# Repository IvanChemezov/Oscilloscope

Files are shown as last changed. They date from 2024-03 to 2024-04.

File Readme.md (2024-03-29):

# Description of the project
Schematic
## Goals:
Learn more about electronics via DIYproject. Technologies which need to be used and learned are: low noise readout electronics, USB as a main data line, space compound. Shielding of pcbs,  wireless connection - additional.

## DIY project:
A portable USB, 1 channel oscilloscope version 1. 

## Activities:
Define Project Requirements;
Conceptualization (diagrams);
Feasibility Study (costs, time);
Define the components for design;
Find and order devboards of the components;
Develop preliminary design of the system;
Prepare and check the schematic;
Order components;
Testing and debugging software;
Prepare and check the pcb layout;
Manufacture the pcb;
Execute test procedure;
Testing and debugging software;
Move to next version of design which includes wireless communication modules;

## Requirements: 
Number of Channels - The oscilloscope should be a single channel.
Bandwidth - The input network bandwidth should support frequencies up to 10 MHz.
Input Impedance - The oscilloscope's input impedance should be 1 MOhm || 15 pF.
Input Signal Range - The acceptable input signal range is -5 V to +5 V.
Time Division -  min. time division of 0.1 us,  max. time 1 seconds.
Vertical Offset - Vertical offset should range from -40 to +40 divisions, with vertical resolution sensitivity set at 40 divisions.
Connector - The oscilloscope should be equipped with a BNC connector for the probes.
ADC Specifications - The ADC resolution > 12 bits, sampling frequency > 10 MHz.
Power Source - The oscilloscope should be powered through a USB Type-A connection.
Display - The device does not have a display. Data shown on a laptop
*Memory Capacity - The oscilloscope's memory capacity should be > 1 MB, TBD, optional*.
Operating Modes - The oscilloscope should support different operating modes, including normal, peak detect, average, and high-resolution modes.

## Design solution
Scope should have a status RGB LED.
Oscilloscope shouldn’t have any user’s buttons or switches
Device should include protection mechanisms against ESD and overloading.
The main processor should be a high performance MCU with maths acceleration functions (ex. STM32G484).
The main ADC should be compatible with pin-to-pin replacements, such as AD9235, ads4122-ads4129, ADC10080 - ADC10040, LTC2245. The ADCs have to have same interface 
Wireless Connectivity - The oscilloscope should include a Wi-Fi chip with support for 802.11n or superior standards.
Components should have minimal footprint.
Pcb needs to be as small as possible, preferable 30 x 20

## Success metrics:
Oscilloscope match the required parameters, technologies are working as estimated

## Reference project
https://www.martinloren.com/hs101-pro-diy-oscilloscope/ 

## Components
Mcu test  
https://eu.mouser.com/ProductDetail/STMicroelectronics/NUCLEO-G474RE?qs=T3oQrply3y%2FWWTZ0gC%252Br%2FA%3D%3D 

## Open questions
https://eu.mouser.com/ProductDetail/STMicroelectronics/STM32G491KCU6?qs=CiayqK2gdcJMDdaGLIKprw%3D%3D controller
https://eu.mouser.com/ProductDetail/Analog-Devices/LTC2225CUHPBF?qs=hVkxg5c3xu%252B3BqQYArDo0w%3D%3D ADC
https://eu.mouser.com/ProductDetail/GigaDevice/GD25D10CEIGR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 memory
https://eu.mouser.com/ProductDetail/Toshiba/TCR15AG33LF?qs=W0yvOO0ixfEdwQi51FhISQ%3D%3D power
https://eu.mouser.com/ProductDetail/Amphenol-RF/112640?qs=g6wJ%252BjiQWOckvE%2FP9L4wAw%3D%3D connector
https://eu.mouser.com/ProductDetail/Masach/MS110-10S?qs=pUKx8fyJudBF3ymdfEXpvw%3D%3D shielding
https://eu.mouser.com/datasheet/2/609/AD8337-3119375.pdf preamplifier
https://eu.mouser.com/ProductDetail/Inolux/IN-S63TBS5R5G5B?qs=stqOd1AaK7%2Fi2QYkhDu%252BwA%3D%3D rgb led
https://eu.mouser.com/ProductDetail/Hirose-Connector/CX60-24S-UNIT?qs=W0yvOO0ixfHwfoCnP4i0Tw%3D%3D usb type C
https://eu.mouser.com/ProductDetail/Analog-Devices/ADA4830-1WBCPZ-R7?qs=pqQDoYZ2quZZWZQMT6uc6g%3D%3D difference amplifier

## Reference designs
https://www.instructables.com/DPScope-Build-Your-Own-USBPC-Based-Oscilloscope/
https://www.bitscope.com/product/BS05/ 
https://github.com/martinloren/HScope/blob/master/HS402/V3.0%2BWifi/Schematic%26PCB/SCH_HS402-WIFI_V3.1_220108.pdf 
https://hackaday.com/2023/10/18/stm32-offers-performance-gains-for-diy-oscilloscope/ 
https://www.youtube.com/watch?v=cVnVtucYcDg&ab_channel=STMicroelectronics

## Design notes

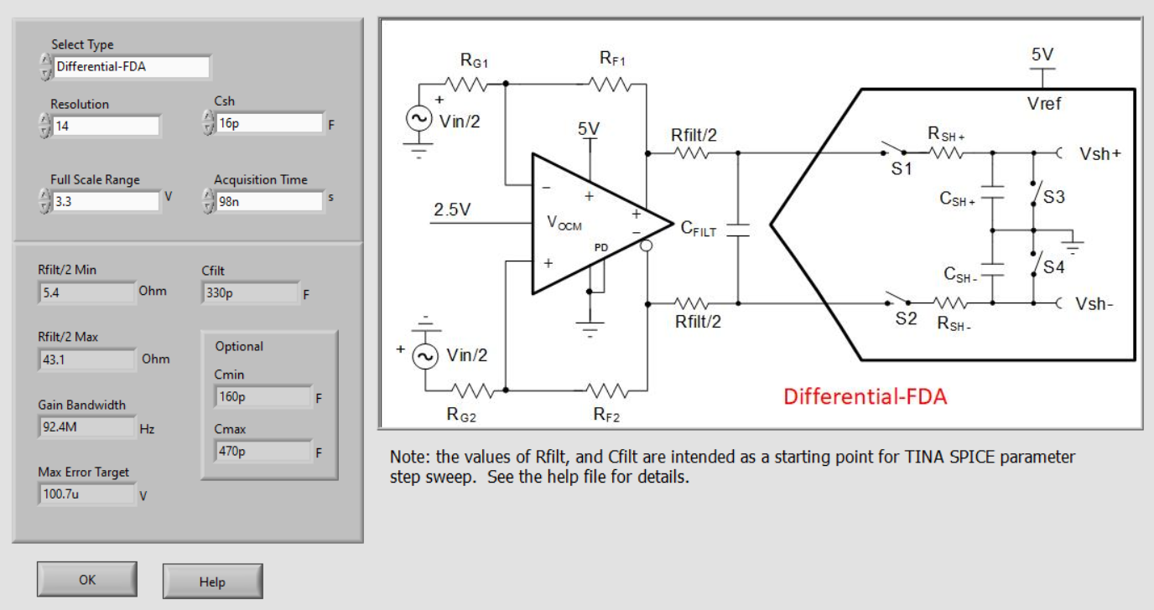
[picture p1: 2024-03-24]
Scope_evtA/Amp.png

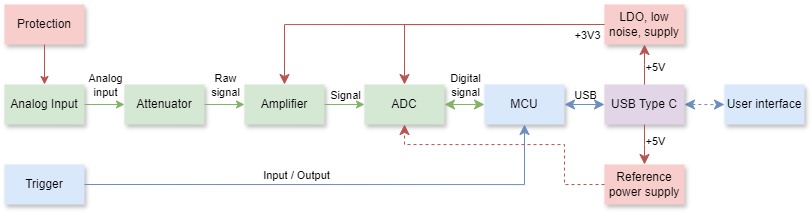
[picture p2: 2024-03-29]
Scope_evtA/scope.jpg

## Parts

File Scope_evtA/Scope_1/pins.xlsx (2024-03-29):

# | Port | Pin | Function | Name | Comment
1 | N/A | N/A | Power | Vdd
2 | C | 13 | NC | N/A
3 | C | 14 | NC | N/A
4 | C | 15 | NC | N/A
5 | F | 0 | OSC+ | N/A
6 | F | 1 | OSC- | N/A
7 | G | 0 | NC | N/A
8 | A | 0 | TIM2_1 | ADC_CLK | Up to 20 MHz
9 | A | 1 | Output | Mode_1 | Twos Complement
10 | A | 2 | Output | Mode_2 | Offset Binary
11 | A | 3 | Comp2_Inp | Trigger
12 | A | 4 | DAC1_1 | Trigger_Out
13 | A | 5 | Input | OTR | From ADC
14 | A | 6 | Output | Sense | Need to be open drain
15 | A | 7 | Output | PDWN | ADC on/off
16 | C | 4 | NC | N/A
17 | B | 0 | Input | D0 | From ADC data line
18 | B | 1 | Input | D1 | From ADC data line
19 | B | 2 | Input | D2 | From ADC data line
20 | N/A | N/A | Power | Vdda
21 | N/A | N/A | Power | Vdda
22 | B | 10 | Input | D10 | From ADC data line
23 | N/A | N/A | Power | Vdd
24 | B | 11 | Input | D11 | From ADC data line
25 | B | 12 | Input | D12 | From ADC data line
26 | B | 13 | Input | D13 | From ADC data line
27 | B | 14 | NC | N/A
28 | B | 15 | NC | N/A
29 | C | 6 | NC | N/A
30 | A | 8 | NC | N/A
31 | A | 9 | TIM1_2 | PWM_LED | For WS2812
32 | A | 10 | Output | USB_Pin | Reboot USB isolator
33 | A | 11 | USB | USB_N
34 | A | 12 | USB | USB_P
35 | N/A | N/A | Power | Vdd
36 | A | 13 | SWDIO | SWDIO
37 | A | 14 | SWCLK | SWCLK
38 | A | 15 | NC | N/A
39 | C | 10 | NC | N/A
40 | C | 11 | NC | N/A
41 | B | 3 | Input | D3 | From ADC data line
42 | B | 4 | Input | D4 | From ADC data line
43 | B | 5 | Input | D5 | From ADC data line
44 | B | 6 | Input | D6 | From ADC data line
45 | B | 7 | Input | D7 | From ADC data line
46 | B | 8 | Input | D8 | From ADC data line
47 | B | 9 | Input | D9 | From ADC data line
48 | N/A | N/A | Power | Vdd
49 | N/A | N/A | Vss | GND

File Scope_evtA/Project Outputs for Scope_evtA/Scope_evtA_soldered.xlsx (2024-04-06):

Comment | P/N | Designator | Footprint | Quantity
0R | SCR0603J0R | R13, R21 | R0603 | 2
0.1u | 06031C104K4T2A | C2, C4, C7, C8, C9, C10, C11, C13, C14, C20, C24, C27, C29, C32, C39, C42, C44, C47, C48, C50, C55, C58, C60, C61, C65, C66, C68, C69, C72, C74, C75, C76, C77, C79 | C0603 | 34
1M | AR03BTCX1004 | R6, R20 | R0603 | 2
1u | C0603X105K025T | C21, C22, C25, C30, C40, C46, C49, C56, C57, C59 | C0603 | 10
1.5k | TC0325B1501T5F | R14, R15, R17 | R0603 | 3
2.2n | 06035C222JAT2A | C5, C16, C34 | C0603 | 3
4.7uF | GRT188C71C475KE13D | C1, C3, C12, C15, C18, C19, C23, C26, C28, C31, C33, C36, C37, C38, C41, C43, C64, C67, C73, C78 | C0603 | 20
5k1 | SCR0603F5K1 | R4, R5, R42 | R0603 | 3
10k | SCR0603J10K | R10, R12, R23, R36, R40 | R0603 | 5
10p | 06035A100DAT2A | C51, C52, C62, C63, C70, C71 | C0603 | 6
20k | SCR0603J20K | R9, R11, R41 | R0603 | 3
22 R | SCR0603J22R | R2, R3, R16, R18, R22, R24, R25, R27, R28, R29, R30, R31, R32, R33, R34, R35, R37, R38, R39, R43, R44, R45, R46, R47, R49, R50, R51 | R0603 | 27
100R | RTT03101JTP | R26, R48 | R0603 | 2
390p | TCC0603COG391J500CT | C6, C17, C35, C45 | C0603 | 4
AD9245BCPZ-20 | AD9245BCPZ-20 | DA3 | LFCSP-32_AD9245 | 1
AP3012KTR-G1 | AP3012KTR-G1 | DD3 | SOT-23-5 | 1
REF35160QDBVR | REF35160QDBVR | DD2 | SOT-23-6 | 1
TPD2EUSB30ADRTR | TPD2EUSB30ADRTR | VD3 | SOT-9X3 | 1
TYPEC-309-ACP16L65 | TYPEC-309-ACP16L65 | J1 | 217179-0001 | 1
WS2812C | WS2812C | VD5 | SMD5050 | 1

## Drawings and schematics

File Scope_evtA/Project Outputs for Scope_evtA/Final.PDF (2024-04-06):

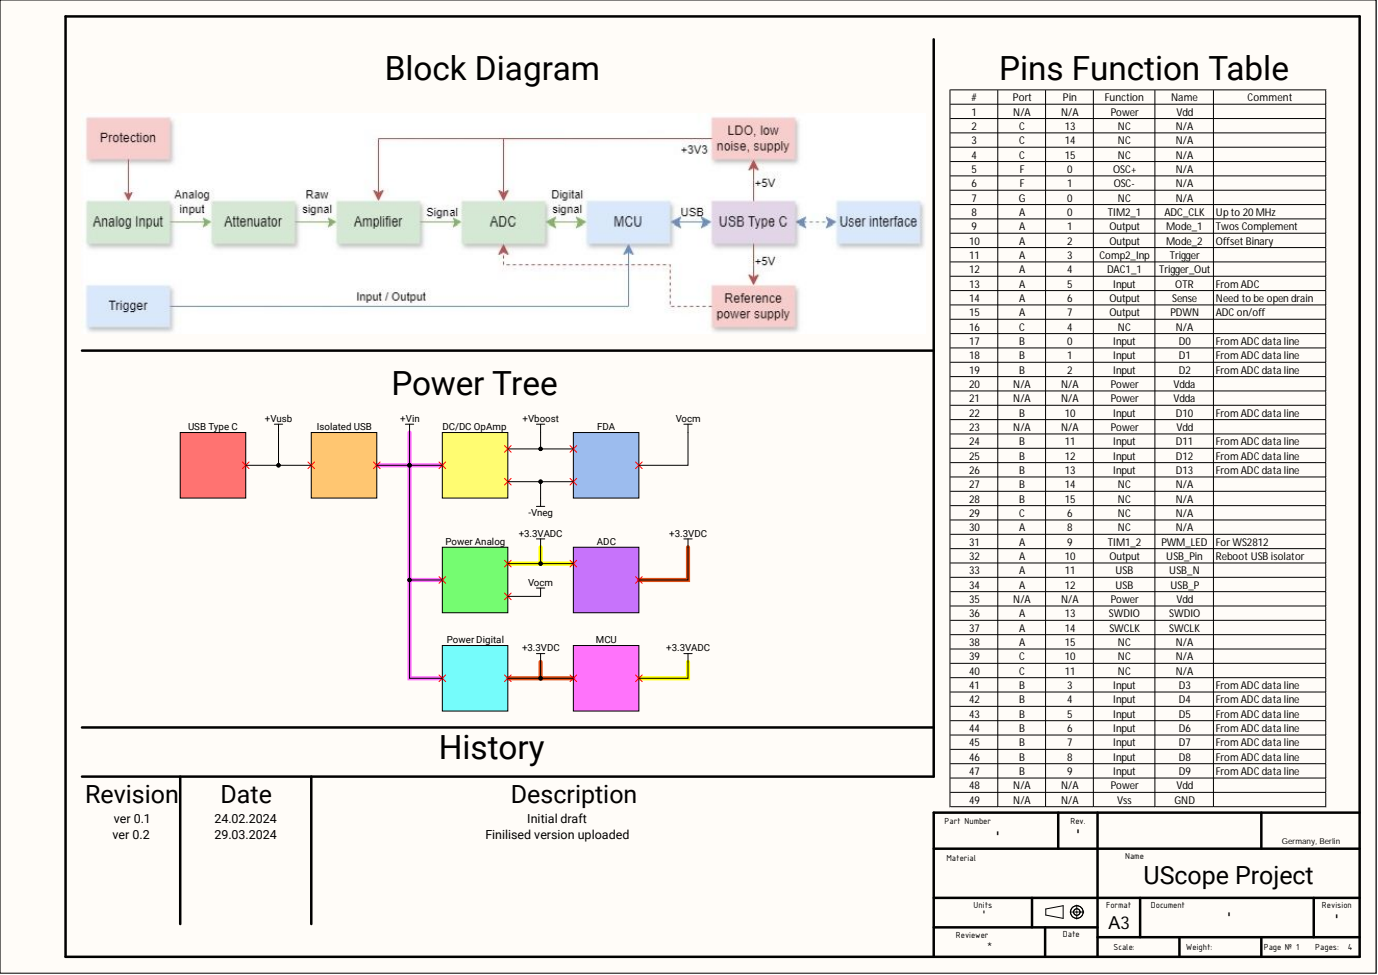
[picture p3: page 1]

# | Port | Pin | Function | Name | Comment
1 | N/A | N/A | Power | Vdd
2 | C | 13 | NC | N/A
3 | C | 14 | NC | N/A
4 | C | 15 | NC | N/A
5 | F | 0 | OSC+ | N/A
6 | F | 1 | OSC- | N/A
7 | G | 0 | NC | N/A
8 | A | 0 | TIM2_1 | ADC_CLK | Up to 20 MHz
9 | A | 1 | Output | Mode_1 | Twos Complement
10 | A | 2 | Output | Mode_2 | Offset Binary
11 | A | 3 | Comp2_Inp | Trigger
12 | A | 4 | DAC1_1 | Trigger_Out
13 | A | 5 | Input | OTR | From ADC
14 | A | 6 | Output | Sense | Need to be open drain
15 | A | 7 | Output | PDWN | ADC on/off
16 | C | 4 | NC | N/A
17 | B | 0 | Input | D0 | From ADC data line
18 | B | 1 | Input | D1 | From ADC data line
19 | B | 2 | Input | D2 | From ADC data line
20 | N/A | N/A | Power | Vdda
21 | N/A | N/A | Power | Vdda
22 | B | 10 | Input | D10 | From ADC data line
23 | N/A | N/A | Power | Vdd
24 | B | 11 | Input | D11 | From ADC data line
25 | B | 12 | Input | D12 | From ADC data line

27 | B | 14 | NC | N/A
28 | B | 15 | NC | N/A
29 | C | 6 | NC | N/A
30 | A | 8 | NC | N/A
31 | A | 9 | TIM1_2 | PWM_LED | For WS2812
32 | A | 10 | Output | USB_Pin | Reboot USB isolator

34 | A | 12 | USB | USB_P
35 | N/A | N/A | Power | Vdd
36 | A | 13 | SWDIO | SWDIO
37 | A | 14 | SWCLK | SWCLK
38 | A | 15 | NC | N/A
39 | C | 10 | NC | N/A
40 | C | 11 | NC | N/A
41 | B | 3 | Input | D3 | From ADC data line
42 | B | 4 | Input | D4 | From ADC data line
43 | B | 5 | Input | D5 | From ADC data line
44 | B | 6 | Input | D6 | From ADC data line
45 | B | 7 | Input | D7 | From ADC data line
46 | B | 8 | Input | D8 | From ADC data line
47 | B | 9 | Input | D9 | From ADC data line
48 | N/A | N/A | Power | Vdd
49 | N/A | N/A | Vss | GND

Part Number ' | Rev. ' | | Germany, Berlin

Material | | Name UScope Project

Units ' | | | | Format А3 | Document | Revision

Reviewer * | | Date

Scale: | Weight: | Page № 1 Pages: 4

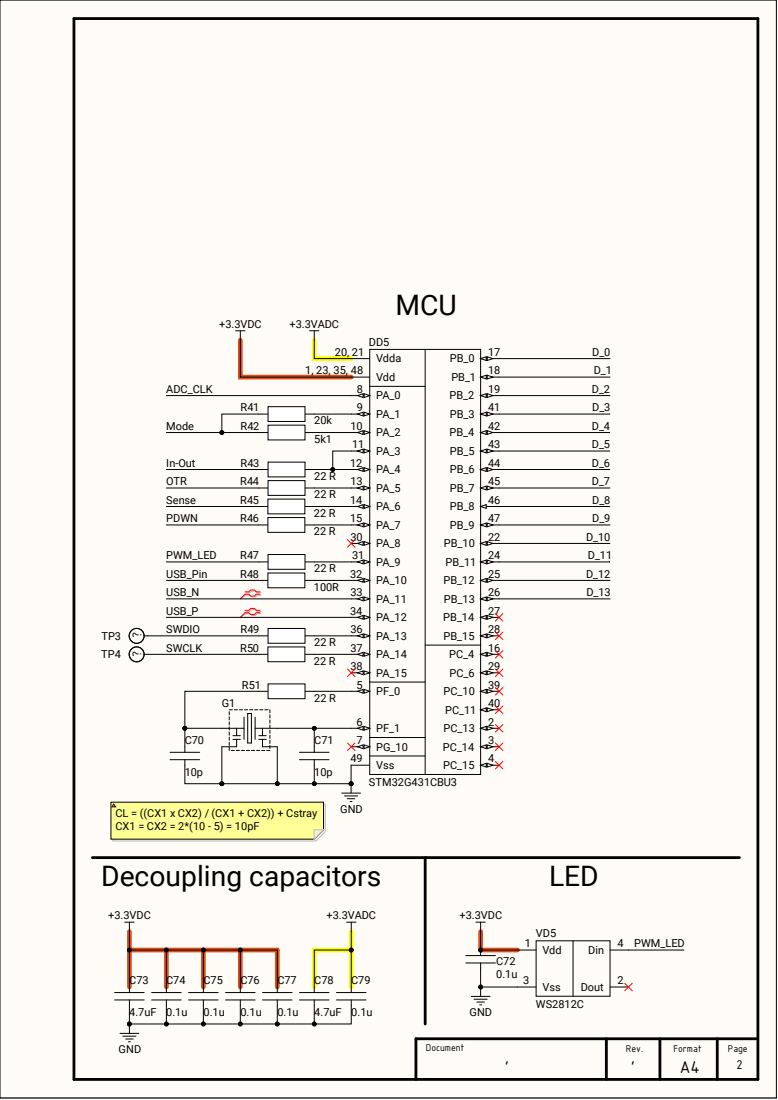
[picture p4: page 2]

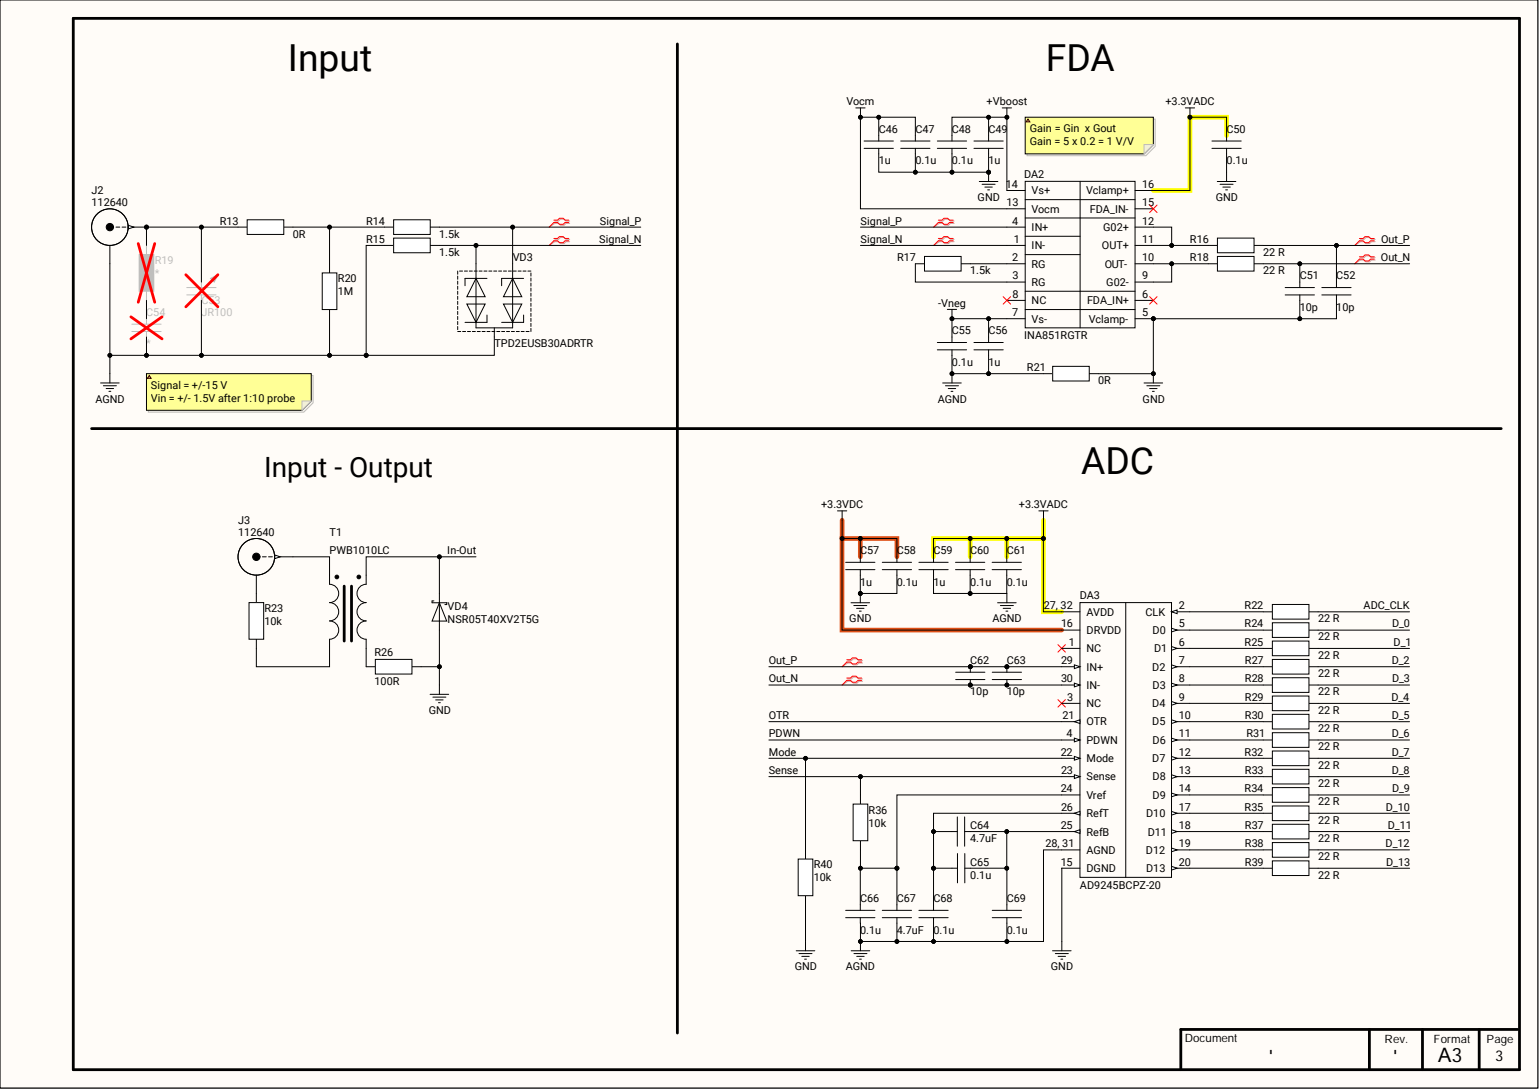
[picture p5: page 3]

RG 3
NC 8
Vs- 7

RefT 26
RefB 25
AGND 28, 31
DGND 15

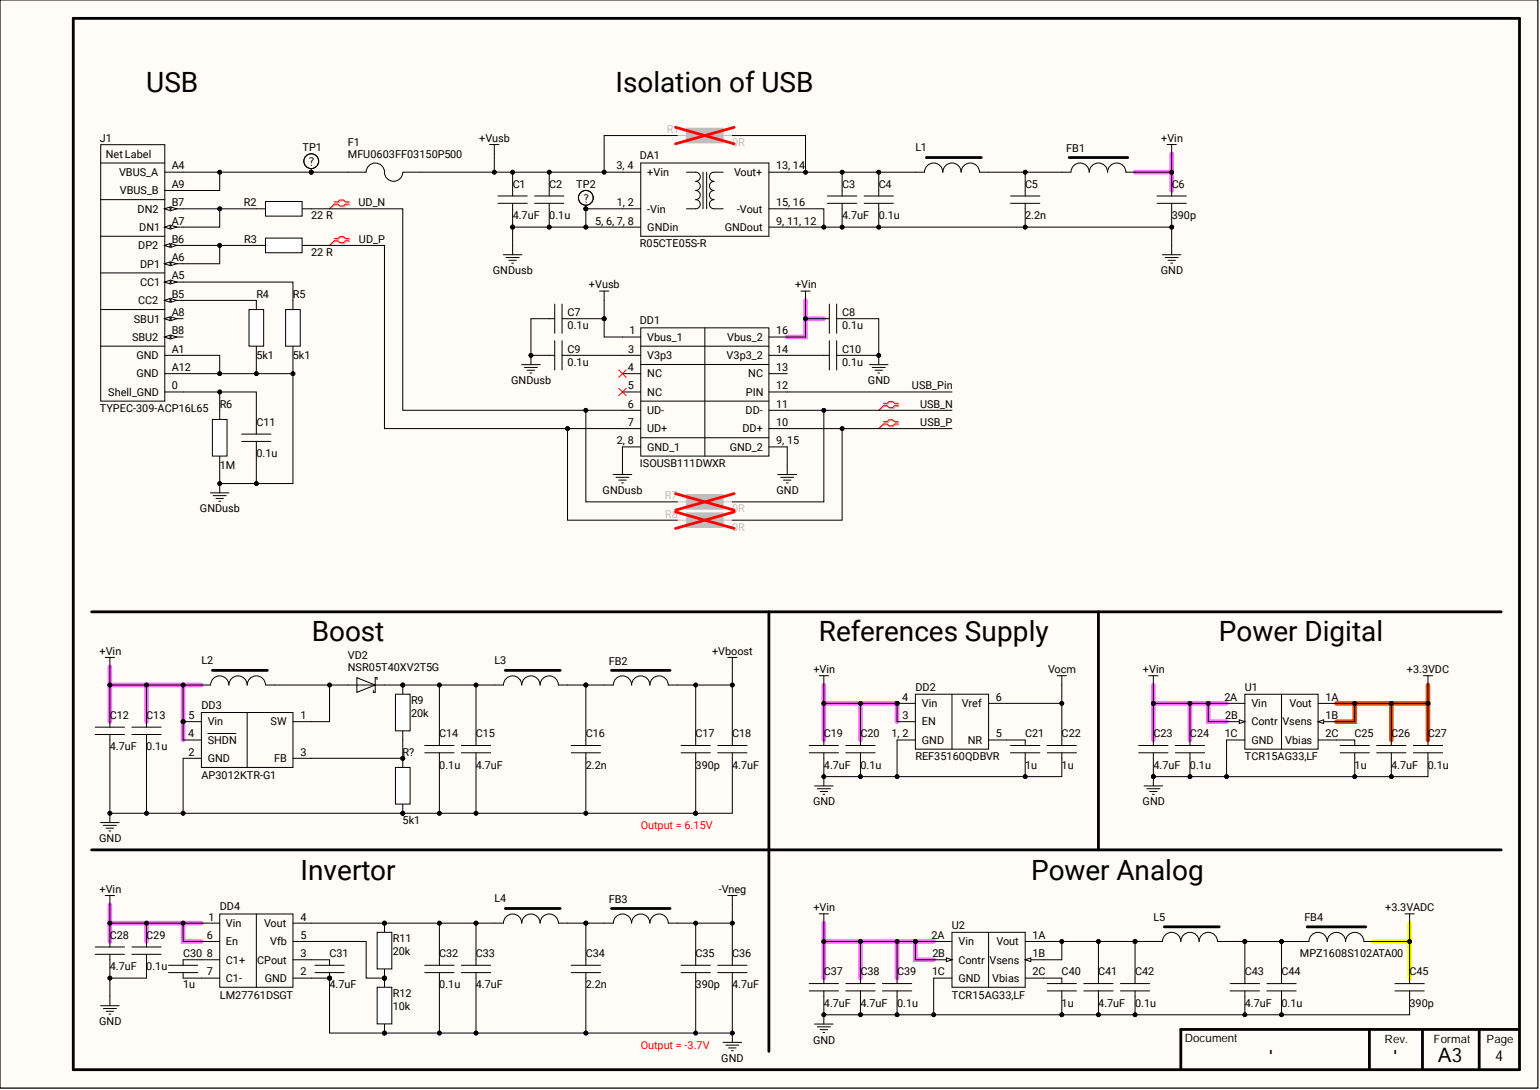
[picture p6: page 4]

+Vin 3, 4

Vbus_1 1
V3p3 3

Vin

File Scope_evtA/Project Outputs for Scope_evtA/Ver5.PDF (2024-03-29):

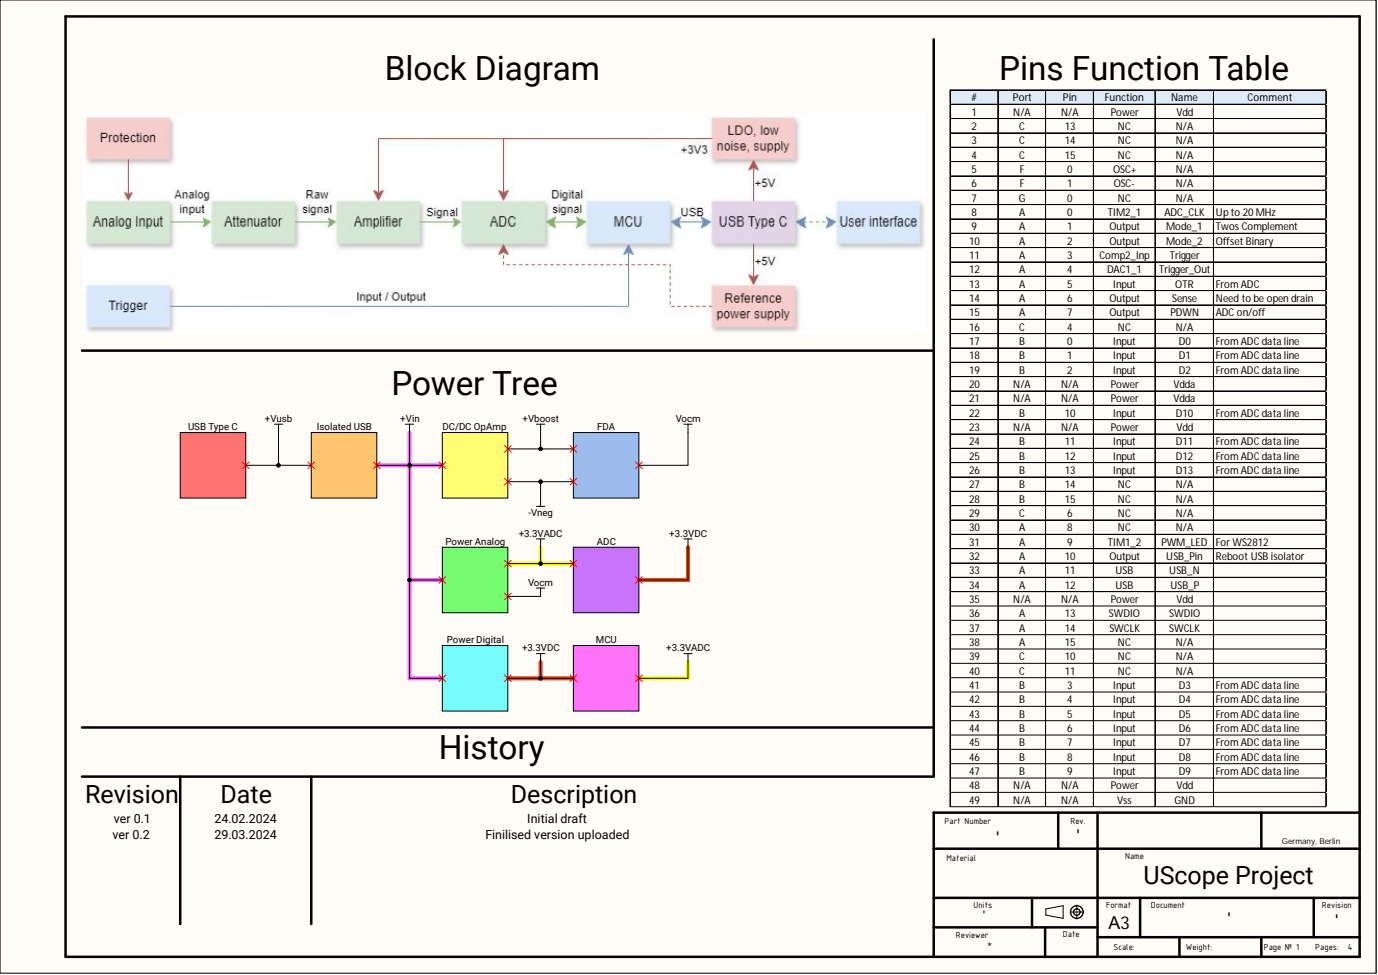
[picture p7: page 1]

# | Port | Pin | Function | Name | Comment
1 | N/A | N/A | Power | Vdd
2 | C | 13 | NC | N/A
3 | C | 14 | NC | N/A
4 | C | 15 | NC | N/A
5 | F | 0 | OSC+ | N/A
6 | F | 1 | OSC- | N/A
7 | G | 0 | NC | N/A
8 | A | 0 | TIM2_1 | ADC_CLK | Up to 20 MHz
9 | A | 1 | Output | Mode_1 | Twos Complement
10 | A | 2 | Output | Mode_2 | Offset Binary
11 | A | 3 | Comp2_Inp | Trigger
12 | A | 4 | DAC1_1 | Trigger_Out
13 | A | 5 | Input | OTR | From ADC
14 | A | 6 | Output | Sense | Need to be open drain
15 | A | 7 | Output | PDWN | ADC on/off
16 | C | 4 | NC | N/A
17 | B | 0 | Input | D0 | From ADC data line
18 | B | 1 | Input | D1 | From ADC data line
19 | B | 2 | Input | D2 | From ADC data line
20 | N/A | N/A | Power | Vdda
21 | N/A | N/A | Power | Vdda
22 | B | 10 | Input | D10 | From ADC data line
23 | N/A | N/A | Power | Vdd
24 | B | 11 | Input | D11 | From ADC data line
25 | B | 12 | Input | D12 | From ADC data line

27 | B | 14 | NC | N/A
28 | B | 15 | NC | N/A
29 | C | 6 | NC | N/A
30 | A | 8 | NC | N/A
31 | A | 9 | TIM1_2 | PWM_LED | For WS2812
32 | A | 10 | Output | USB_Pin | Reboot USB isolator

34 | A | 12 | USB | USB_P
35 | N/A | N/A | Power | Vdd
36 | A | 13 | SWDIO | SWDIO
37 | A | 14 | SWCLK | SWCLK
38 | A | 15 | NC | N/A
39 | C | 10 | NC | N/A
40 | C | 11 | NC | N/A
41 | B | 3 | Input | D3 | From ADC data line
42 | B | 4 | Input | D4 | From ADC data line
43 | B | 5 | Input | D5 | From ADC data line
44 | B | 6 | Input | D6 | From ADC data line
45 | B | 7 | Input | D7 | From ADC data line
46 | B | 8 | Input | D8 | From ADC data line
47 | B | 9 | Input | D9 | From ADC data line
48 | N/A | N/A | Power | Vdd
49 | N/A | N/A | Vss | GND

Part Number ' | Rev. ' | | Germany, Berlin

Material | | Name UScope Project

Units ' | | | | Format А3 | Document | Revision

Reviewer * | | Date

Scale: | Weight: | Page № 1 Pages: 4

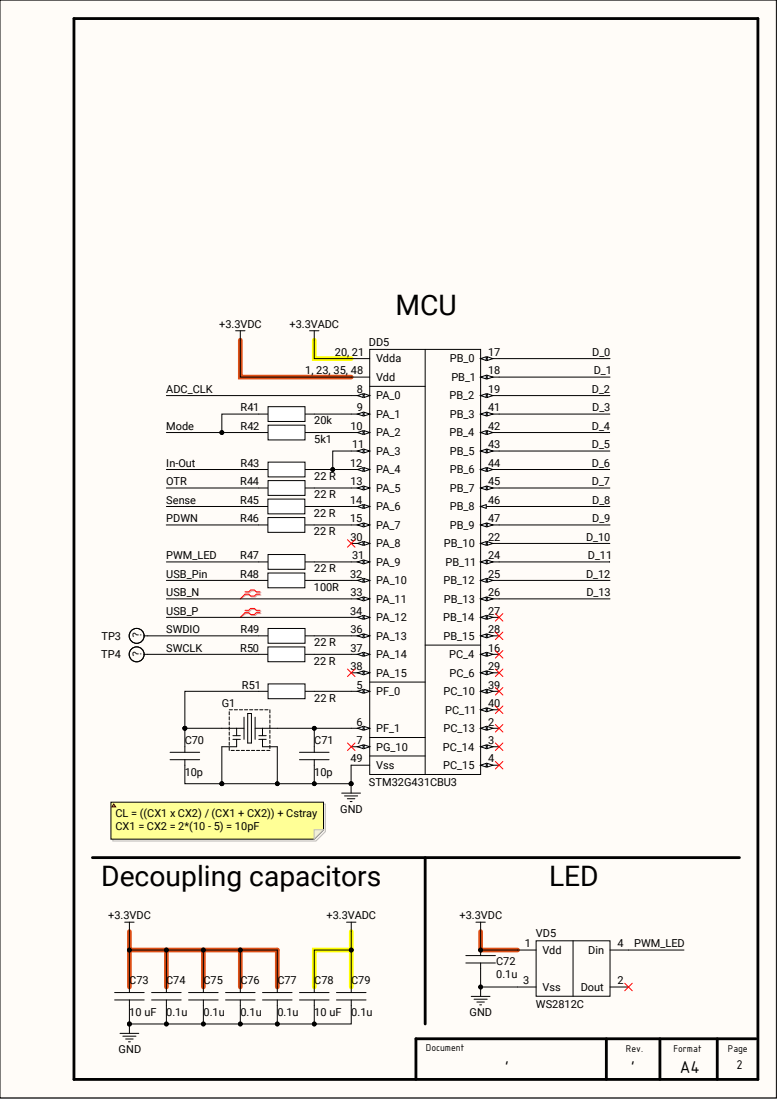
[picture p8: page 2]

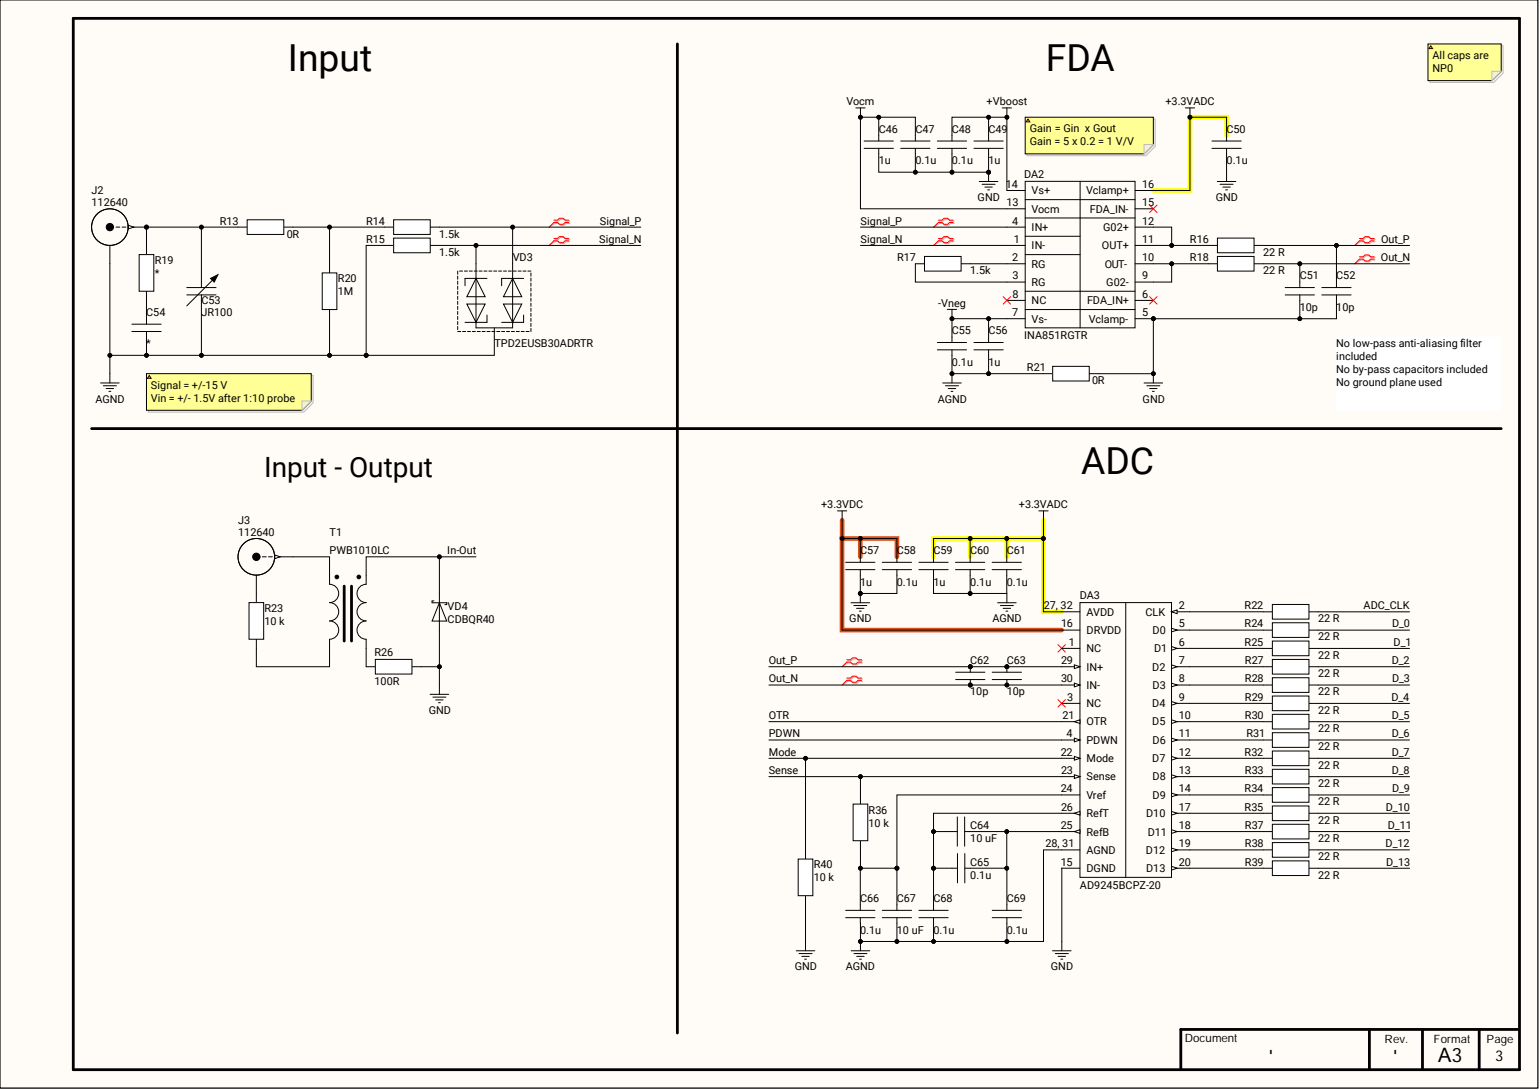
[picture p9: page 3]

RG 3
NC 8
Vs- 7

No low-pass anti-aliasing filter
included
No by-pass capacitors included
No ground plane used

RefT 26
RefB 25
AGND 28, 31
DGND 15

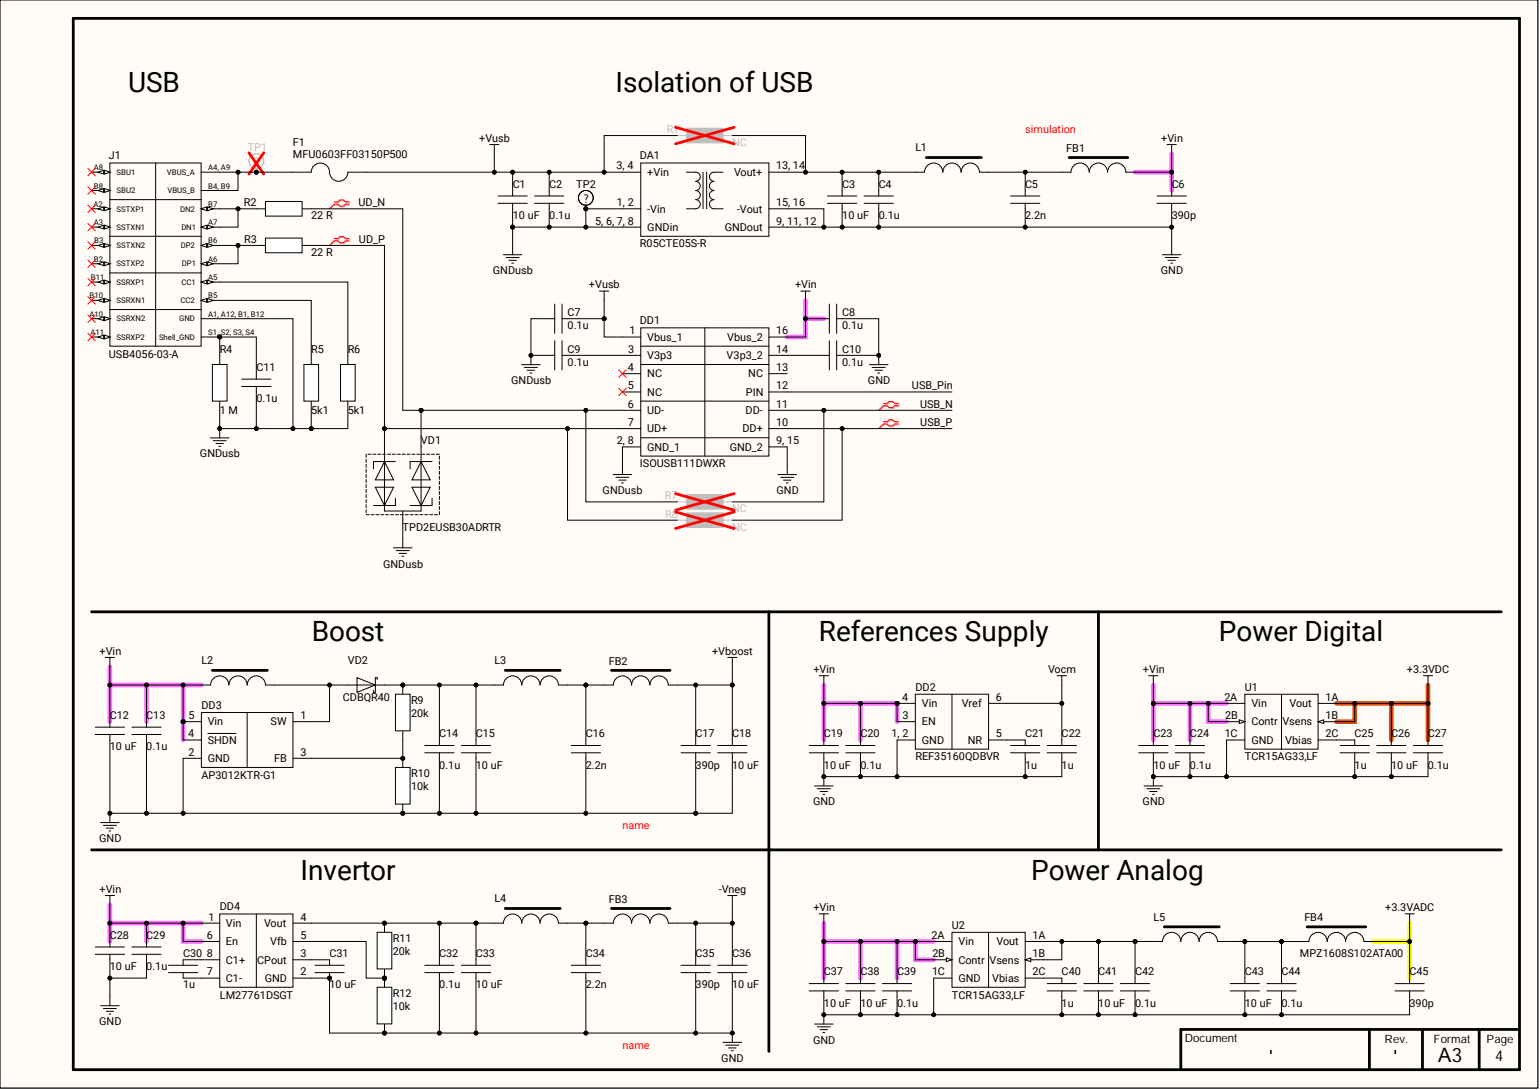
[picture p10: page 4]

C1 | ? | -Vin 1, 2

SSTXP1 A2 SSTXN1 A3

SSTXN2 B3 SSTXP2 B2

SSRXN2 A10 SSRXP2 A11 | GND

Vbus_1 1
V3p3 3

Vin

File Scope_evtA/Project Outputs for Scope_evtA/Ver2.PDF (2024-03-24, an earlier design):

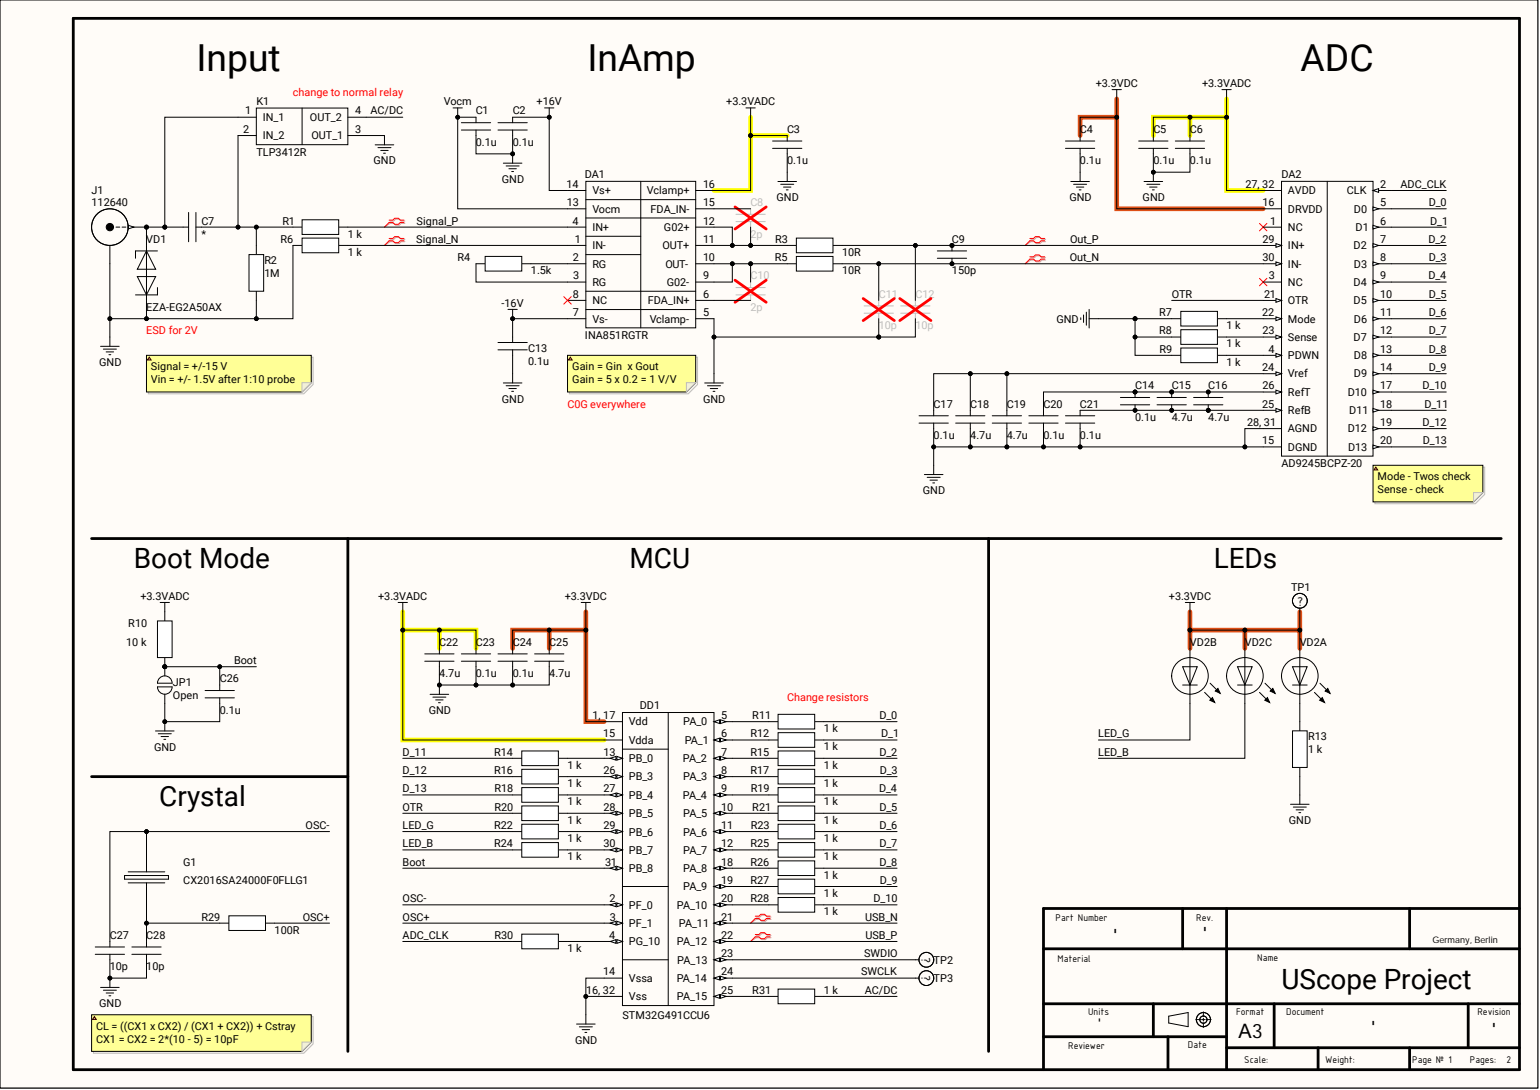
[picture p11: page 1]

change to normal relay

Vocm
IN+ 4

NC 8
Vs- 7

C17 | C18 | C14 C15 C16 | RefT 26

RefB 25

0.1u | 0.1u | | DGND 15

Part Number ' | Rev. ' | | Germany, Berlin

Material | | Name UScope Project

Vss 16, 32

Units ' | | | | Format А3 | Document ' | Revision '

Reviewer | | Date

Scale: | Weight: | Page № 1 Pages: 2

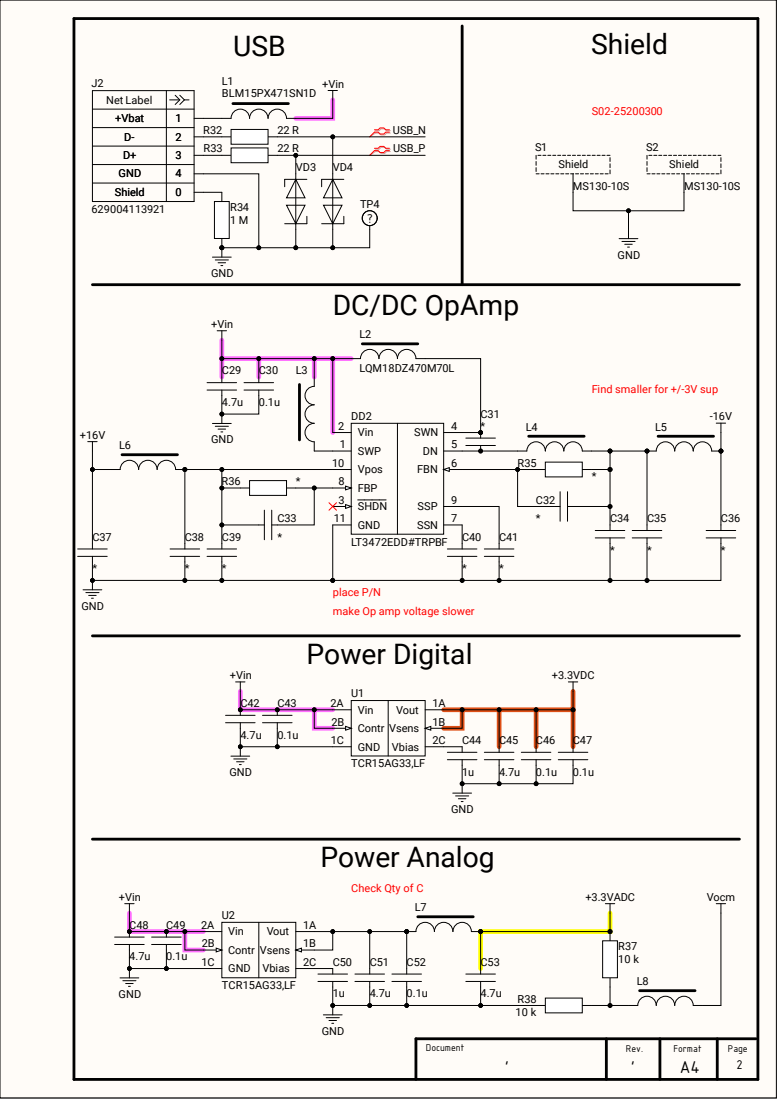
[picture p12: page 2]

Net Label
+Vbat | 1
D- | 2
D+ | 3
GND | 4
Shield | 0

Find smaller for +/-3V sup

SWP 1 | SSP

SHDN 3

place P/N
make Op amp voltage slower
Power Digital

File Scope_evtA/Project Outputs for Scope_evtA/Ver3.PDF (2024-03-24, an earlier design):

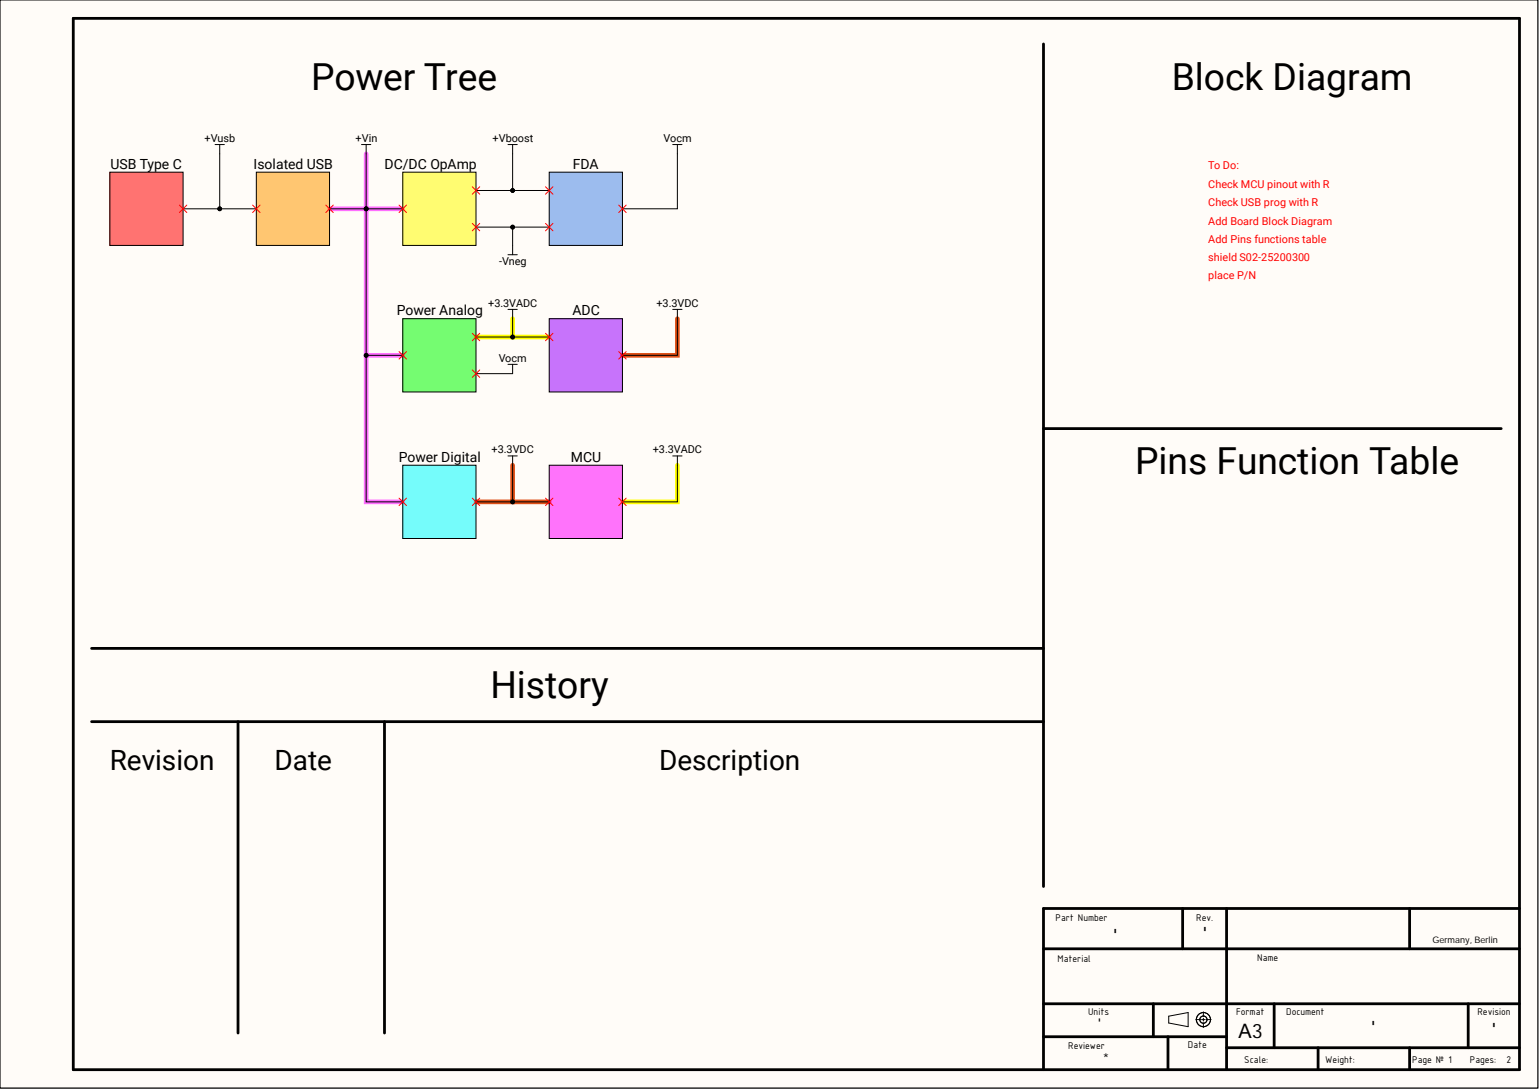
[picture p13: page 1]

Check MCU pinout with R
Check USB prog with R
Add Board Block Diagram
Add Pins functions table
shield S02-25200300
place P/N

Part Number ' | Rev. ' | | Germany, Berlin

Material | | Name

Units ' | | | | Format А3 | Document | Revision

Reviewer * | | Date

Scale: | Weight: | Page № 1 Pages: 2

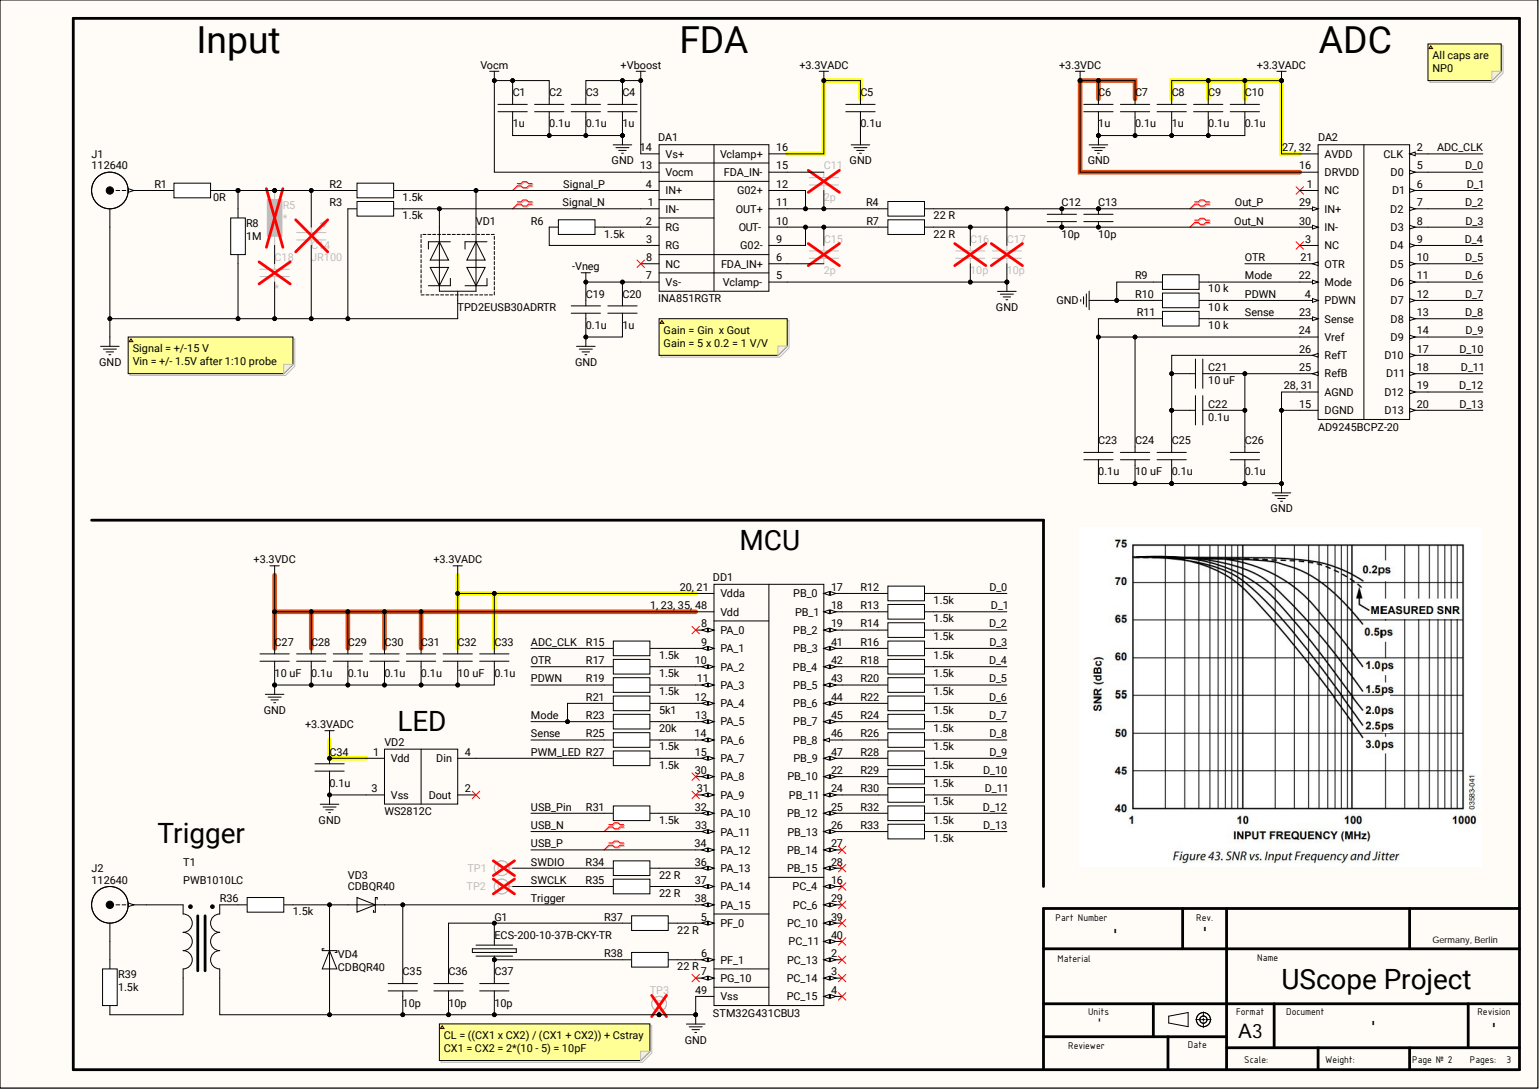
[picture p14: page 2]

Vocm
IN+ 4

NC 8
Vs- 7

C23 | | | RefT 26

RefB 25
AGND 28, 31
DGND 15

Vdda 20, 21

Part Number ' | Rev. ' | | Germany, Berlin

Material | | Name UScope Project

Units | | | | Revision

Reviewer | | Date

Scale: | Weight: | Page № 2 Pages: 3


SSTXN2 B3

A5 | GNDusb

SSRXP1 B11 | CC1 CC2
SSRXN1 B10 | | B5 | R43

SSRXN2 A10 | GND

Calculations are in excel

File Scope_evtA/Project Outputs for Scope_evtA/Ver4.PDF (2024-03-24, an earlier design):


# | Port | Pin | Function | Name | Comment
1 | N/A | N/A | Power | Vdd
2 | C | 13 | NC | N/A
3 | C | 14 | NC | N/A
4 | C | 15 | NC | N/A
5 | F | 0 | OSC+ | N/A
6 | F | 1 | OSC- | N/A
7 | G | 0 | NC | N/A
8 | A | 0 | NC | N/A
9 | A | 1 | TIM2_2 | ADC_CLK | Up to 20 MHz
10 | A | 2 | Input | OTR | From ADC
11 | A | 3 | Output | PDWN | ADC on/off
12 | A | 4 | Output | Mode_1 | Twos Complement
13 | A | 5 | Output | Mode_2 | Offset Binary
14 | A | 6 | Output | Sense | Need to be open drain
15 | A | 7 | TIM17_1 | PWM_LED | For WS2812
16 | C | 4 | NC | N/A
17 | B | 0 | Input | D0 | From ADC data line
18 | B | 1 | Input | D1 | From ADC data line
19 | B | 2 | Input | D2 | From ADC data line
20 | N/A | N/A | Power | Vdda
21 | N/A | N/A | Power | Vdda
22 | B | 10 | Input | D10 | From ADC data line
23 | N/A | N/A | Power | Vdd
24 | B | 11 | Input | D11 | From ADC data line
25 | B | 12 | Input | D12 | From ADC data line
26 | B | 13 | Input | D13 | From ADC data line

30 | A | 8 | NC | N/A
31 | A | 9 | Output | Output
32 | A | 10 | Output | USB_Pin | Reboot USB isolator
33 | A | 11 | USB | USB_N
34 | A | 12 | USB | USB_P
35 | N/A | N/A | Power | Vdd
36 | A | 13 | SWDIO | SWDIO
37 | A | 14 | SWCLK | SWCLK
38 | A | 15 | EXTI15 | Trigger
39 | C | 10 | NC | N/A
40 | C | 11 | NC | N/A
41 | B | 3 | Input | D3 | From ADC data line
42 | B | 4 | Input | D4 | From ADC data line
43 | B | 5 | Input | D5 | From ADC data line
44 | B | 6 | Input | D6 | From ADC data line
45 | B | 7 | Input | D7 | From ADC data line
46 | B | 8 | Input | D8 | From ADC data line
47 | B | 9 | Input | D9 | From ADC data line
48 | N/A | N/A | Power | Vdd
49 | N/A | N/A | Vss | GND

Check MCU pinout with R
Check USB prog with R
shield S02-25200300
place P/N

Part Number ' | Rev. ' | | Germany, Berlin

Material | | Name UScope Project

Units ' | | | | Format А3 | Document | Revision

Reviewer * | | Date

Scale: | Weight: | Page № 1 Pages: 3


Vocm
IN+ 4

NC 8
Vs- 7

DGND 15 | D_13

Vdda 20, 21


SSTXN2 B3

A5 | GNDusb

SSRXP1 B11 | CC1 CC2
SSRXN1 B10 | | B5 | R4

SSRXN2 A10 | GND

Calculations are in excel

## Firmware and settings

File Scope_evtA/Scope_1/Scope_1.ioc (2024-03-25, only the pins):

Mcu.UserName=STM32G431CBUx
PA0.GPIO_Label=ADC_CLK
PA0.Signal=S_TIM2_CH1
PA1.GPIO_Label=Mode_1
PA1.Signal=GPIO_Output
PA10.GPIO_Label=USB_pin
PA10.Signal=GPIO_Output
PA11.Signal=USB_DM
PA12.Signal=USB_DP
PA13.Signal=SYS_JTMS-SWDIO
PA14.Signal=SYS_JTCK-SWCLK
PA2.GPIO_Label=Mode_2
PA2.Signal=GPIO_Output
PA3.GPIO_Label=Input_Trigger
PA3.Signal=COMP2_INP
PA4.GPIO_Label=Output_Trigger
PA4.Signal=COMP_DAC11_group
PA5.GPIO_Label=OTR
PA5.Signal=GPIO_Input
PA6.GPIO_Label=Sense
PA6.Signal=GPIO_Input
PA7.GPIO_Label=PDWN
PA7.Signal=GPIO_Output
PA9.GPIO_Label=LED_PWM
PA9.Signal=S_TIM1_CH2
PB0.GPIO_Label=D_0
PB0.Signal=GPIO_Input
PB1.GPIO_Label=D_1
PB1.Signal=GPIO_Input
PB10.GPIO_Label=D_10
PB10.Signal=GPIO_Input
PB11.GPIO_Label=D_11
PB11.Signal=GPIO_Input
PB12.GPIO_Label=D_12
PB12.Signal=GPIO_Input
PB13.GPIO_Label=D_13
PB13.Signal=GPIO_Input
PB2.GPIO_Label=D_2
PB2.Signal=GPIO_Input
PB3.GPIO_Label=D_3
PB3.Signal=GPIO_Input
PB4.GPIO_Label=D_4
PB4.Signal=GPIO_Input
PB5.GPIO_Label=D_5
PB5.Signal=GPIO_Input
PB6.GPIO_Label=D_6
PB6.Signal=GPIO_Input
PB7.GPIO_Label=D_7
PB7.Signal=GPIO_Input
PB8-BOOT0.GPIO_Label=D_8
PB8-BOOT0.Signal=GPIO_Input
PB9.GPIO_Label=D_9
PB9.Signal=GPIO_Input
PF0-OSC_IN.Signal=RCC_OSC_IN
PF1-OSC_OUT.Signal=RCC_OSC_OUT

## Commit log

2024-03-24 initial upload
    initial upload
    [ADP5072.xlsx, INA851-Input-and-Output-Range-Calc-revA.xlsx, Power budget.xlsx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]
2024-03-29 Finilised version is uploaded
    reworked layout design
    remoced comparators
    [Scope_evtA.PrjPcb]
2024-03-29 updated table
    [pins.xlsx]
2024-04-06 final version was uploaded
    new usb type c
    better layout
    gerber and assembly files added
    [EVT_A.GBL, EVT_A.GBO, EVT_A.GBP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]
